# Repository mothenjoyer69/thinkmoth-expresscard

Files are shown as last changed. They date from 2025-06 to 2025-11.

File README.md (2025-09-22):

# ThinkMoth Expresscard to NVMe 
An ExpressCard to NVMe adapter, except this one actually ships! 

The ThinkMoth ExpressCard to NVMe is a low cost, open source adapter for using an M.2 2230/2242 NVMe SSD in an ExpressCard34/54 socket. It features a microSD card slot to enable booting from the SSD, and optional status LEDs for SD and PCIe activity so you can look at cool lights. 

Up to PCIe 3.0 @ 1x is supported (it'll be 2.0 on nearly every machine, though), and the only limitation on drives is power consumption. This board will only provide ~1a @ 3.3v, which can cause issues with higher-performance SSDs.

It also includes a yet-to-be-designed 3D printed chassis, with an EC54-specific version also in the works!

Please note that this board *only* supports NVMe drives!

Update 20/9/25:
Prototype PCBs have been ordered :) 

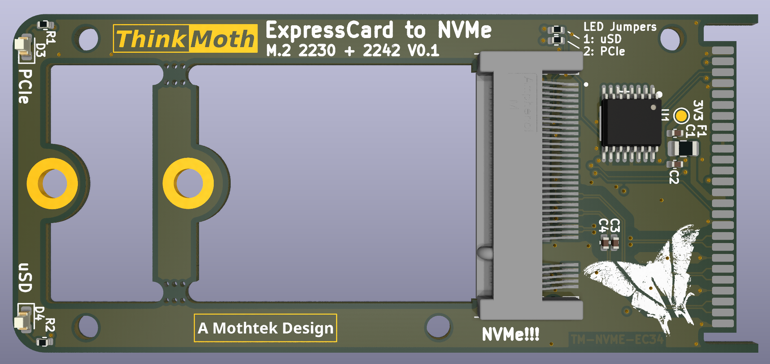
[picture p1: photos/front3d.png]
Front render

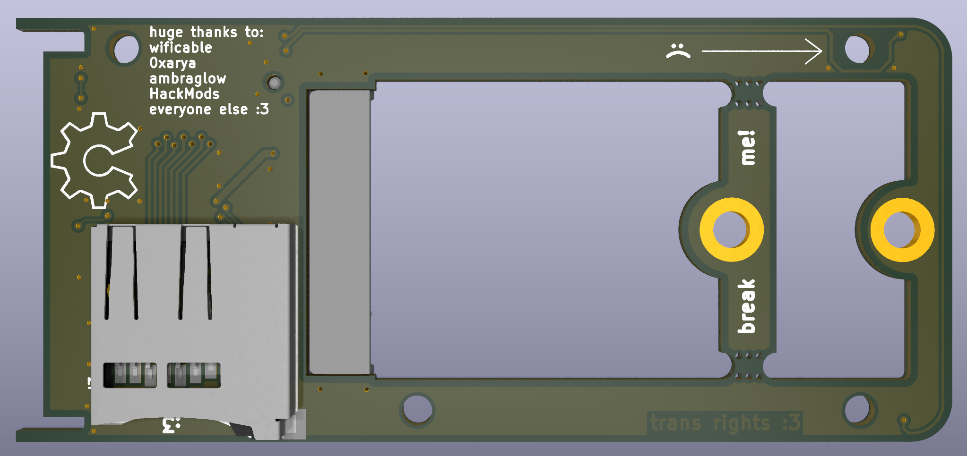
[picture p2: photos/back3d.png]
Back render


# More info:
1. What SSD works best?:
    - ExpressCard is super power limited with only 3v3@1A available to the SSD, so anything slower/low power drives should work fine. Higher end drives might have issues. This adapter only provides a PCIe 1x link, so there isn't much reason to get the high end drives.
2. How does booting from the SSD work?
    - Booting from the SSD works either via a bootloader being installed on the microSD card, which then loads the OS from the SSD. Alternatively, if you are able to add custom drivers, you can use the NVMe driver via Coreboot or similar for basically native operation.
3. When will it be available to buy?
    - I'm planning on having a small batch available in mid October!

# To-do
- Order intitial prototype PCBs [*]
- List on Tindie/Lectronex [ ]
- Alternate versions? [ ]

# Part list:
| Part | Model | Link |
|---|---|---|
| ExpressCard connector  | Amphenol  10030570-2112LF | https://www.arrow.com/en/products/10030570-2112lf/amphenol-fci |
| Mid-mount M.2 M-key | Amphenol MDT180M03001 | https://www.digikey.com.au/en/products/detail/amphenol-cs-fci/MDT180M03001/5810365 |
| SD card controller | Genesys Logic GL823K | https://www.lcsc.com/product-detail/C284879.html |
| microSD card socket | Sofng TF-009 | https://www.lcsc.com/product-detail/C428466.html |
| 1.5A fuse | BHFuse BSMD0805L-150 | https://www.lcsc.com/product-detail/C914095.html |
| 2x 4k 6.3v resistor | Yageo RC0402FR-073KL | https://www.lcsc.com/product-detail/C137987.html |
| 2x 0r 6.3v resistor | Panasonic ERJ2GE0R00X | https://www.lcsc.com/product-detail/C242160.html |
| 4x 0.1uF 6.3v capacitor| Yageo CC0402KRX7R7BB104 | https://www.lcsc.com/product-detail/C60474.html |
| Blue LED | Meihua MHT192WDT-ICE | https://www.lcsc.com/product-detail/C389522.html |
| Pink LED | Xinglight XL-1608UPC-06 | https://www.lcsc.com/product-detail/C2977076.html |

# Doing it yourself:
Wanna do it yourself? Check back here after I've validated the prototype boards, and I'll have a copy of the production gerber .zip, as well as the JLCPCB order settings required!

# Credits
A very big thank you to [Ambra](https://github.com/ambraglow/) for the original board outline, cutout, and EC footprint, and also to [Wifi](https://github.com/a-little-wifi/) and [Arya](https://github.com/CRImier/) and everyone else for all of the help and advice :3

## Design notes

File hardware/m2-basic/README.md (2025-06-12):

# ThinkMoth M.2 2242
An ExpressCard 34/54 board with support for a single M.2 2242 NVMe SSD.

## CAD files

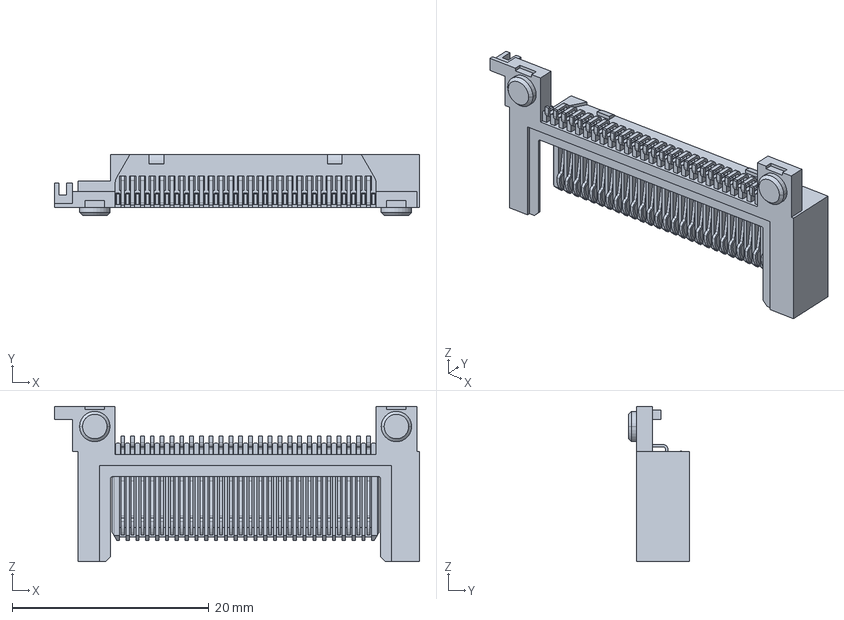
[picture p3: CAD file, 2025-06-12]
hardware/3d-models/c-1759181-1-b-3d.stp
37.1 x 6.20 x 15.8 mm

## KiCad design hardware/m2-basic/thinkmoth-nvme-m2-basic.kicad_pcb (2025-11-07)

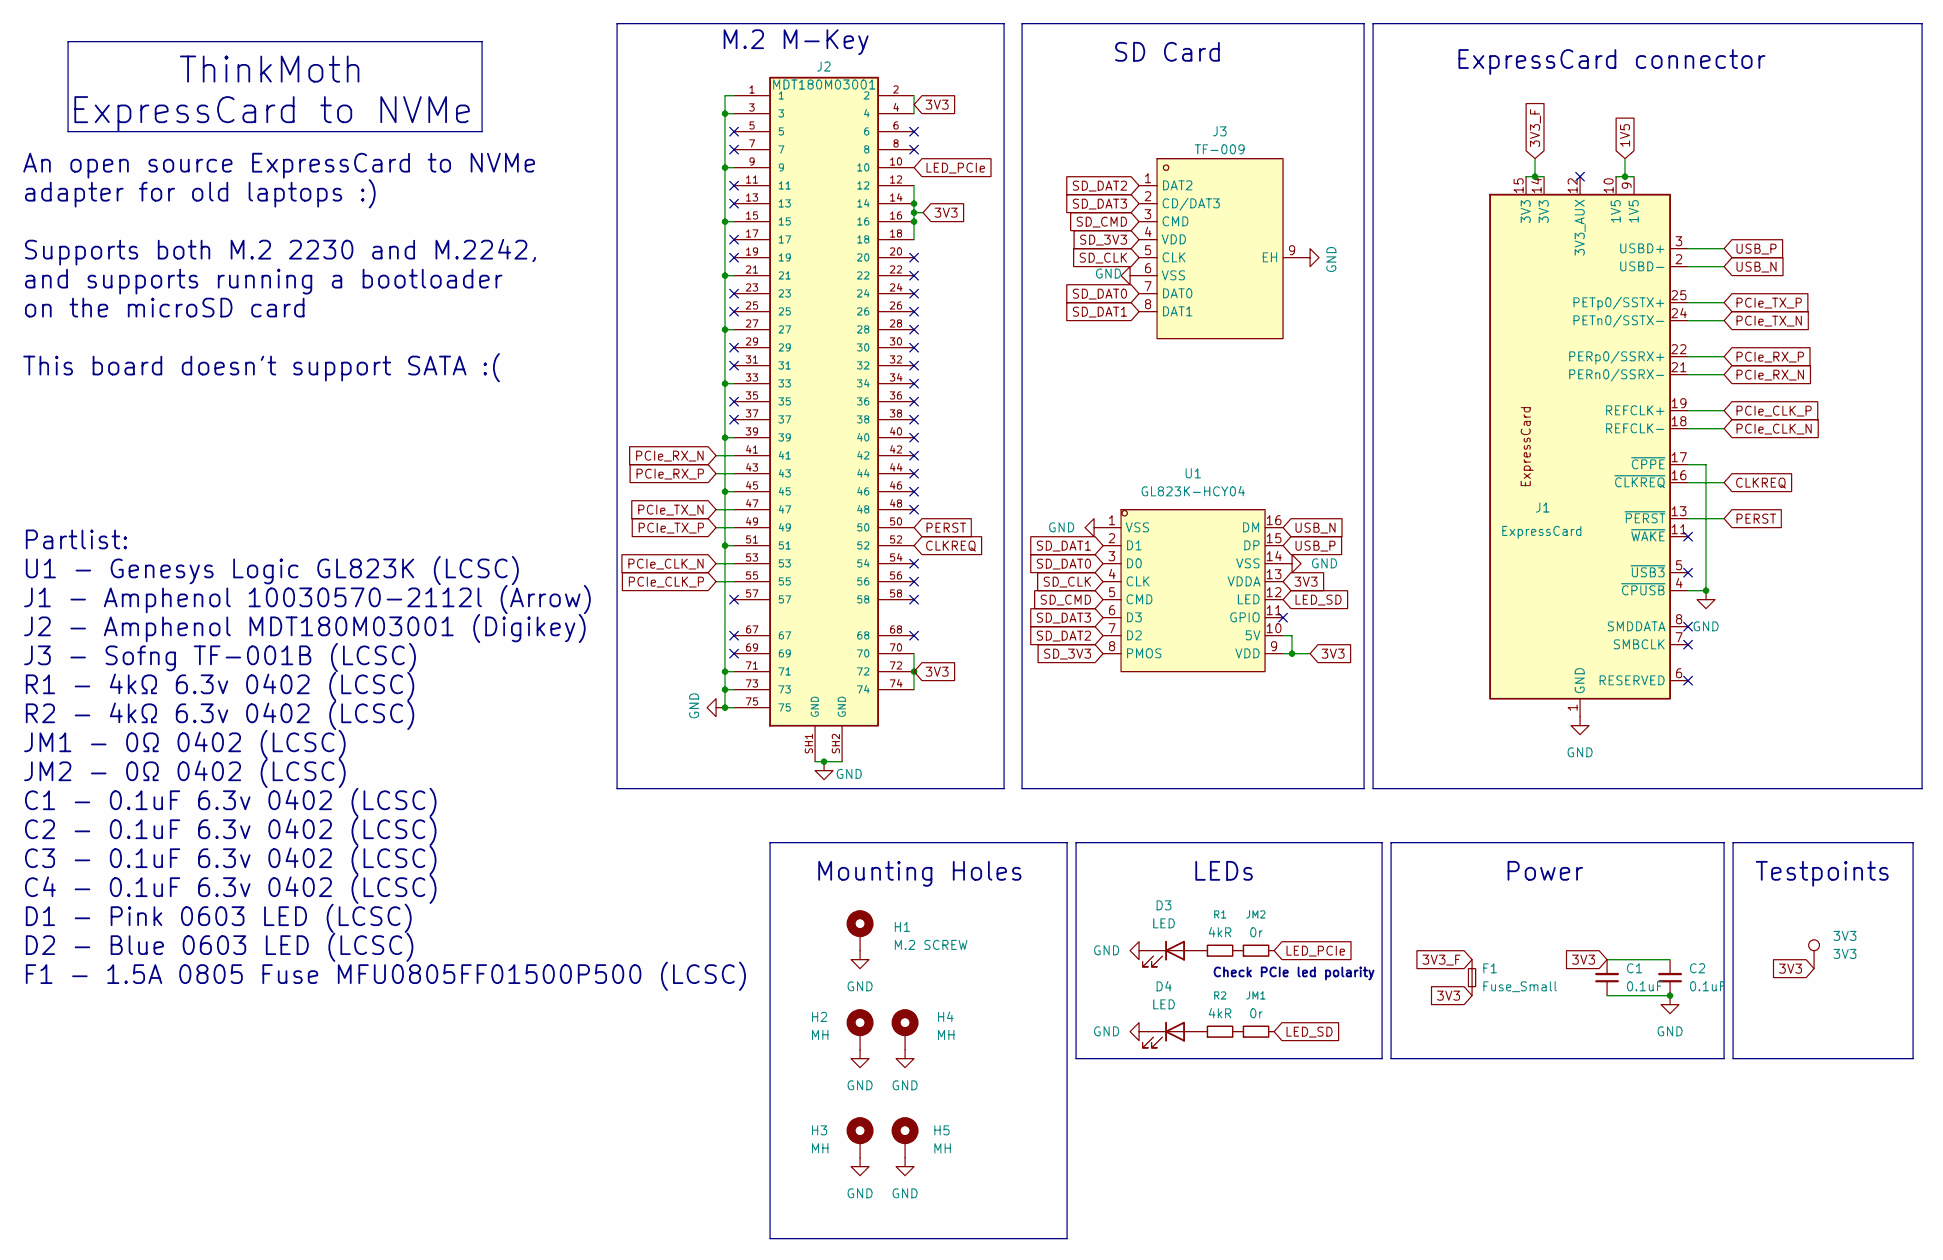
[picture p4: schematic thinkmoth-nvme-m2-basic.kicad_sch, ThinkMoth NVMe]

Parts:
3V3: 3V3; TestPoint_Pad_D1.0mm
C1, C2: 0.1uF; C_0402_1005Metric
D3, D4: LED; LED_0603_1608Metric
F1: Fuse_Small; Fuse_0805_2012Metric
H1: M.2 SCREW; MountingHole_2.7mm_M2.5_DIN965_Pad
H2, H3, H4, H5: MH; MountingHole_2.2mm_M2
J1: ExpressCard; ExpressCard_Plug
J2: MDT180M03001; AMPHENOL_MDT180M03001; PARTREV 2
J3: TF-009; TF-SMD_TF-009; LCSC Part C428466
JM1, JM2: 0r; R_0402_1005Metric
R1, R2: 4kR; R_0402_1005Metric
U1: GL823K-HCY04; SSOP-16_L4.9-W3.9-P0.64-LS6.0-BL; LCSC Part C284879

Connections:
1V5: J1.9 (1V5), J1.10 (1V5)
3V3: 3V3.1, C1.2, C2.2, F1.1, J2.2, J2.4, J2.12, J2.14, J2.16, J2.18, J2.70, J2.72, J2.74, U1.9 (VDD), U1.10 (5V), U1.13 (VDDA)
3V3_F: F1.2, J1.14 (3V3), J1.15 (3V3)
CLKREQ: J1.16 (~CLKREQ), J2.52
GND: C1.1, C2.1, D3.1 (K), D4.1 (K), H1.1, H2.1, H3.1, H4.1, H5.1, J1.1 (GND), J1.4 (~CPUSB), J1.17 (~CPPE), J1.20 (GND), J1.23 (GND), J1.26 (GND), J2.1, J2.3, J2.9, J2.15, J2.21, J2.27, J2.33, J2.39, J2.45, J2.51, J2.71, J2.73, J2.75, J2.SH1 (GND), J2.SH2 (GND), J3.6 (VSS), J3.9 (EH), U1.1 (VSS), U1.14 (VSS)
LED_PCIe: J2.10, JM2.2
LED_SD: JM1.2, U1.12 (LED)
unnamed: D3.2 (A), R1.1
unnamed: D4.2 (A), R2.1
unnamed: JM1.1, R2.2
unnamed: JM2.1, R1.2
PCIe_CLK_N: J1.18 (REFCLK-), J2.53
PCIe_CLK_P: J1.19 (REFCLK+), J2.55
PCIe_RX_N: J1.21 (PERn0/SSRX-), J2.41
PCIe_RX_P: J1.22 (PERp0/SSRX+), J2.43
PCIe_TX_N: J1.24 (PETn0/SSTX-), J2.47
PCIe_TX_P: J1.25 (PETp0/SSTX+), J2.49
PERST: J1.13 (~PERST), J2.50
SD_3V3: J3.4 (VDD), U1.8 (PMOS)
SD_CLK: J3.5 (CLK), U1.4 (CLK)
SD_CMD: J3.3 (CMD), U1.5 (CMD)
SD_DAT0: J3.7 (DAT0), U1.3 (D0)
SD_DAT1: J3.8 (DAT1), U1.2 (D1)
SD_DAT2: J3.1 (DAT2), U1.7 (D2)
SD_DAT3: J3.2 (CD/DAT3), U1.6 (D3)
USB_N: J1.2 (USBD-), U1.16 (DM)
USB_P: J1.3 (USBD+), U1.15 (DP)

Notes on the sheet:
ThinkMoth ExpressCard to NVMe
Mounting Holes
Power
Check PCIe led polarity
M.2 M-Key
An open source ExpressCard to NVMe adapter for old laptops :) Supports both M.2 2230 and M.2242, and supports running a bootloader on the microSD card This board doesn't support SATA :( Partlist: U1 - Genesys Logic GL823K (LCSC) J1 - Amphenol 10030570-2112l (Arrow) J2 - Amphenol MDT180M03001 (Digik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
Testpoints
LEDs
ExpressCard connector
SD Card

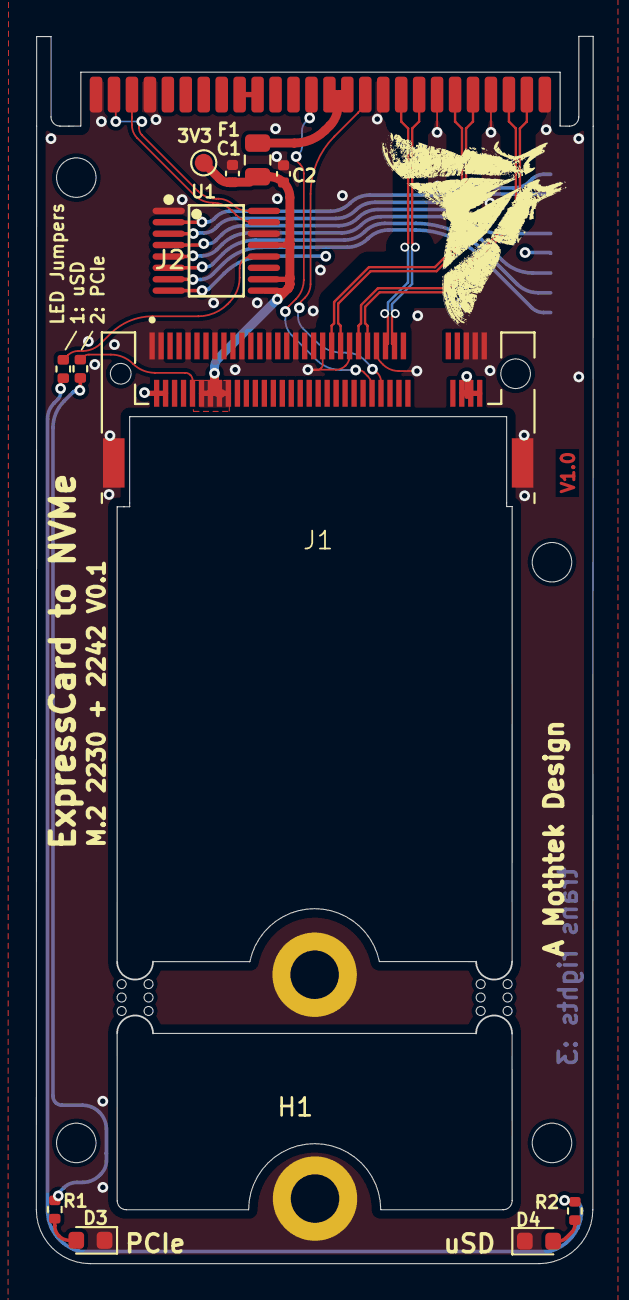
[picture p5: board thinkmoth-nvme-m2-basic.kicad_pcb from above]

Board: 4 copper layers, 31.0 x 68.4 mm, 21 parts (1 on the bottom side), 27 nets.

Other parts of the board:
mouse-bite-2mm-slot, mouse-bite-2mm-slot#2: VAL**; mouse-bite-2mm-slot

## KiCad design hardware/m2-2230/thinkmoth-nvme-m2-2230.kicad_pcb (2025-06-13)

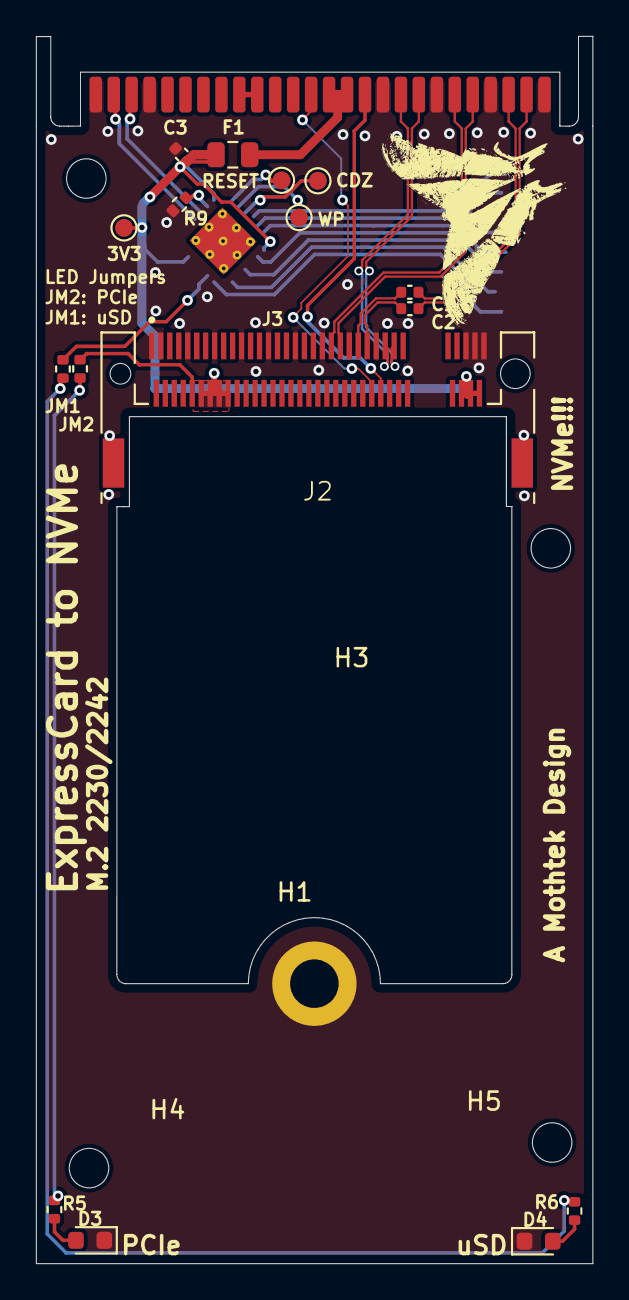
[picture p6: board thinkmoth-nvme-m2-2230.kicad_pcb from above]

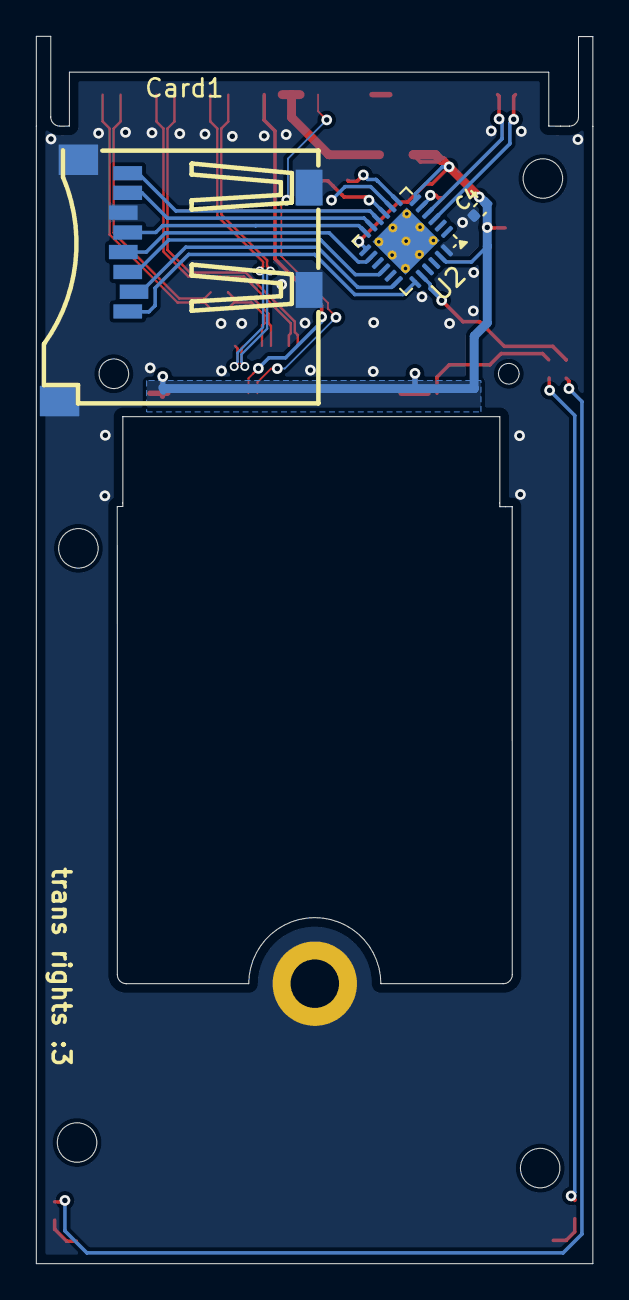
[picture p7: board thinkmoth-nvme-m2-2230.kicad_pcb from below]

Board: 2 copper layers, 31.0 x 68.4 mm, 25 parts (3 on the bottom side), 33 nets.

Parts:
3V3: 3V3; TestPoint_Pad_D1.0mm
C1, C2, C3, C4: 0.1uF; C_0402_1005Metric
CDZ: SD_CDZ; TestPoint_Pad_D1.0mm
Card1: TF-001B; TF-SMD_TF-001B
D3, D4: LED; LED_0603_1608Metric
F1: Fuse_Small; Fuse_0805_2012Metric
H1: M.2 SCREW; MountingHole_2.7mm_M2.5_DIN965_Pad
H2, H3, H4, H5: MOUNTING SCREW; MountingHole_2.2mm_M2
J2: ExpressCard; ExpressCard_Plug
J3: MDT180M03001; AMPHENOL_MDT180M03001
JM1, JM2: 0r; R_0402_1005Metric
R5, R6: 4kR; R_0402_1005Metric
R9: 680r; R_0402_1005Metric
RESET: SD_RESET; TestPoint_Pad_D1.0mm
U2: QFN-24-1EP_4x4mm_P0.5mm_EP2.7x2.6mm_ThermalVias
WP: SD_WP; TestPoint_Pad_D1.0mm

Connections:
1V5: J2.9 (1V5), J2.10 (1V5)
3V3: 3V3.1, C3.2, C4.2, F1.1, J3.2, J3.4, J3.12, J3.14, J3.16, J3.18, J3.70, J3.72, J3.74, U2.6 (AVDD), U2.13 (DVDD), U2.23 (DVDD)
3V3_F: F1.2, J2.14 (3V3), J2.15 (3V3)
CLKREQ: J2.16 (~CLKREQ), J3.52
GND: C3.1, C4.1, Card1.6 (VSS), Card1.9 (SHIELD), Card1.10 (SHIELD), Card1.11 (SW), Card1.12 (SW), D3.1 (K), D4.1 (K), H1.1, J2.1 (GND), J2.4 (~CPUSB), J2.17 (~CPPE), J2.20 (GND), J2.23 (GND), J2.26 (GND), J3.1, J3.3, J3.9, J3.15, J3.21, J3.27, J3.33, J3.39, J3.45, J3.51, J3.71, J3.73, J3.75, R9.1, U2.24 (GND)
unnamed: D3.2 (A), R5.1
unnamed: D4.2 (A), R6.1
unnamed: JM1.1, R6.2
unnamed: JM2.1, R5.2
unnamed: R9.2, U2.5 (RREF)
PCIe_CLK_N: J2.18 (REFCLK-), J3.53
PCIe_CLK_P: J2.19 (REFCLK+), J3.55
PCIe_LED: J3.10, JM2.2
PCIe_RX_N: J2.21 (PERn0/SSRX-), J3.41
PCIe_RX_P: J2.22 (PERp0/SSRX+), J3.43
PCIe_TX_C_N: C1.1, J2.24 (PETn0/SSTX-)
PCIe_TX_C_P: C2.1, J2.25 (PETp0/SSTX+)
PCIe_TX_N: C1.2, J3.47
PCIe_TX_P: C2.2, J3.49
PERST: J2.13 (~PERST), J3.50
SD_3V3: Card1.4 (VDD), U2.14 (PMOS)
SD_CDZ: CDZ.1, U2.9 (SD_CDZ)
SD_CLK: Card1.5 (CLK), U2.12 (SD_CLK)
SD_CMD: Card1.3 (CMD), U2.16 (SD_CMD)
SD_DAT0: Card1.7 (DAT0), U2.11 (D0)
SD_DAT1: Card1.8 (DAT1), U2.10 (D1)
SD_DAT2: Card1.1 (DAT2), U2.19 (D2)
SD_DAT3: Card1.2 (CD/DAT3), U2.18 (D3)
SD_LED: JM1.2, U2.20 (LED)
SD_RESET: RESET.1, U2.7 (RSTZ)
SD_WP: U2.8 (SD_WP), WP.1
USB_N: J2.2 (USBD-), U2.3 (DM)
USB_P: J2.3 (USBD+), U2.4 (DP)

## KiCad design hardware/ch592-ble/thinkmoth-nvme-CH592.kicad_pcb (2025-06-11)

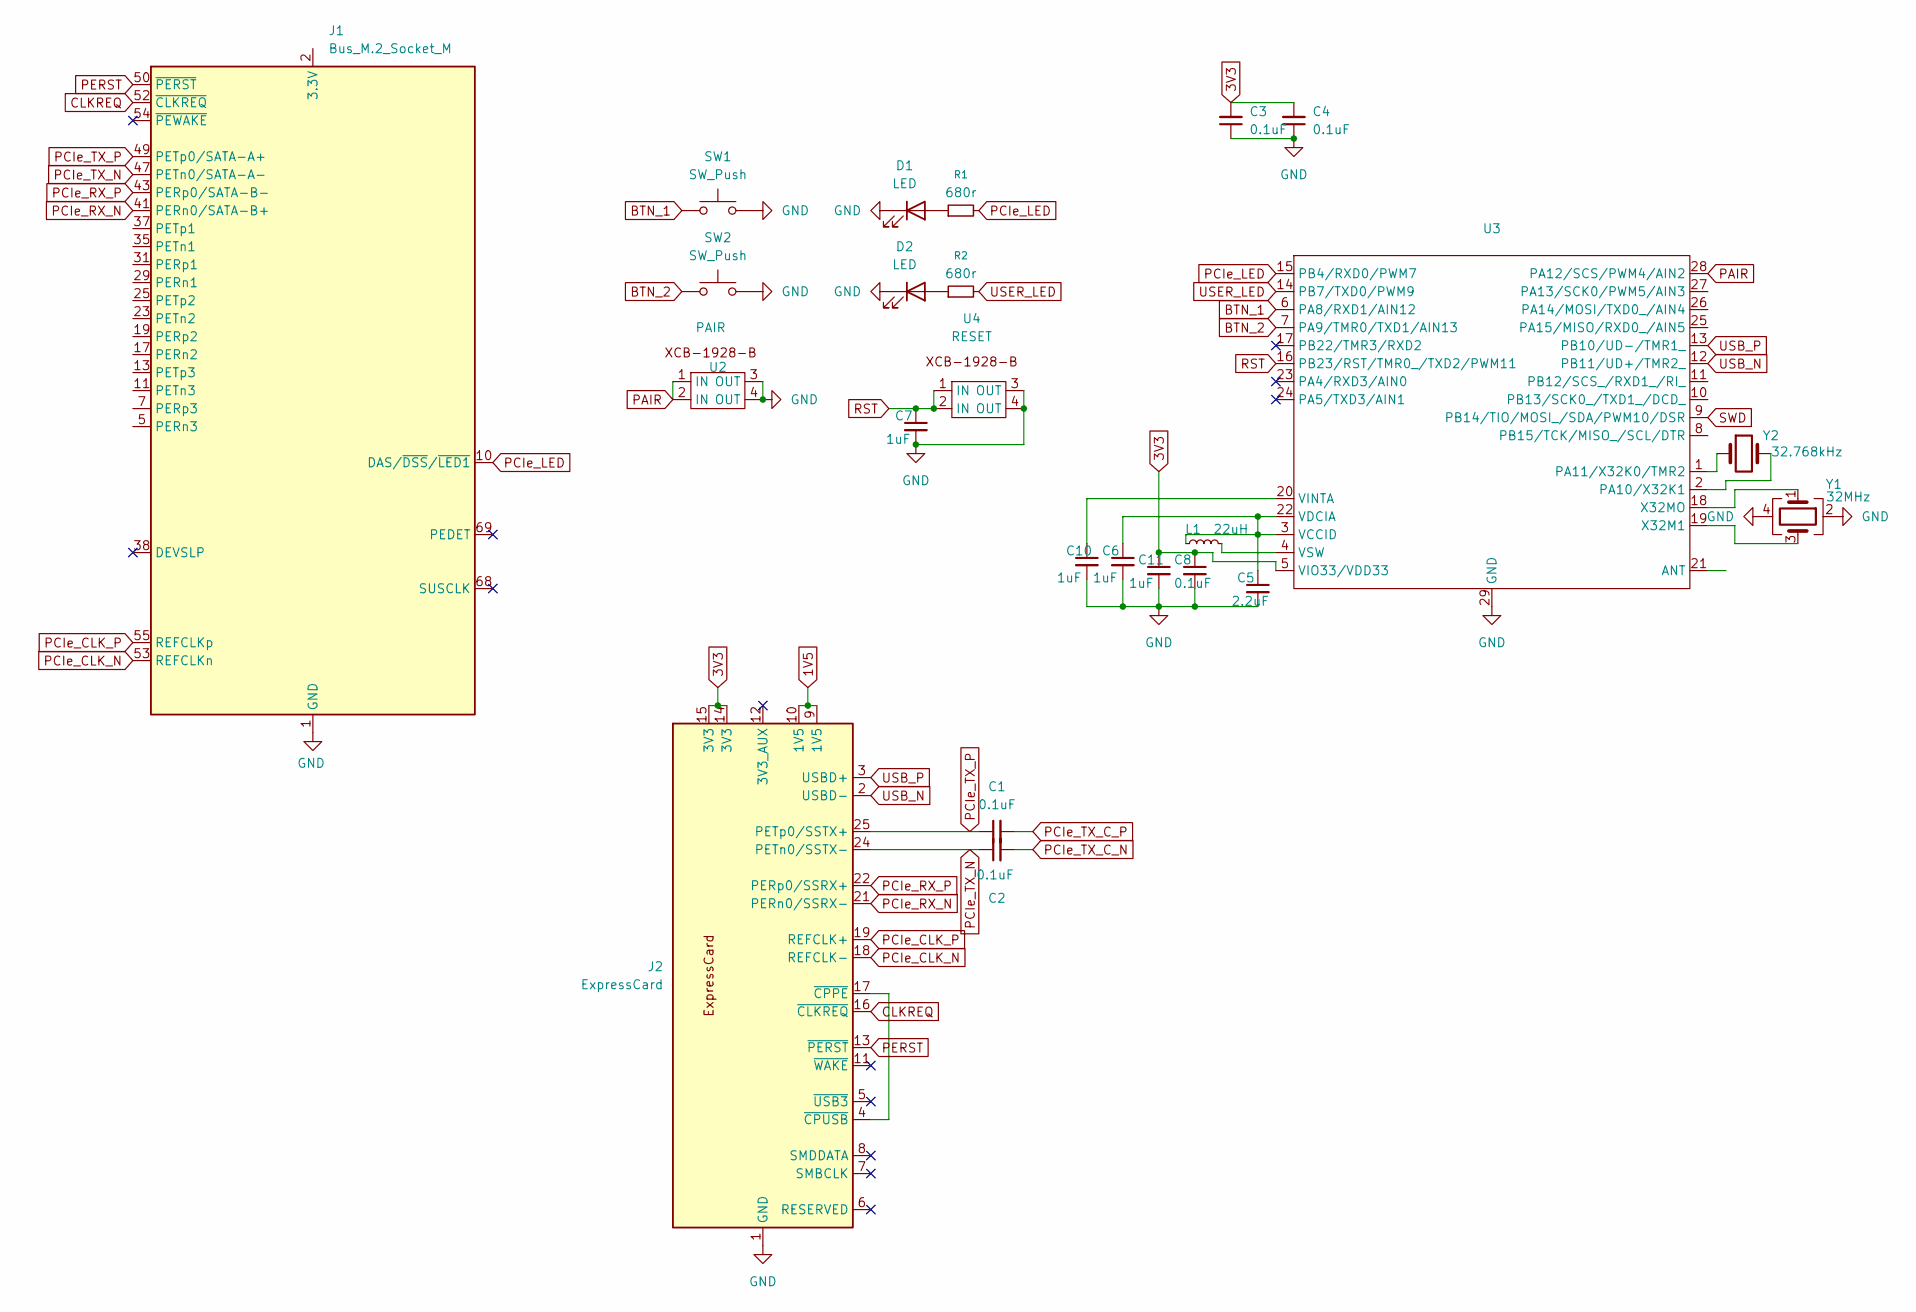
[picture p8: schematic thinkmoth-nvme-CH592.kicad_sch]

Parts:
C1, C2, C3, C4, C8: 0.1uF; C_0402_1005Metric
C5: 2.2uF; C_0402_1005Metric
C6, C7, C10, C11: 1uF; C_0402_1005Metric
D1, D2: LED; LED_0402_1005Metric
J1: Bus_M.2_Socket_M; CONN-SMD_APCI0159-P001A
J2: ExpressCard; ExpressCard_Plug
L1: 22uH; L_0603_1608Metric
R1, R2: 680r; R_0402_1005Metric
SW1, SW2: SW_Push
U2: PAIR; KEY-SMD_4P-L2.8-W2.0-P1.20-LS3.0-TL
U3: QFN-28-1EP_4x4mm_P0.4mm_EP2.3x2.3mm
U4: RESET; KEY-SMD_4P-L2.8-W2.0-P1.20-LS3.0-TL
Y1: 32MHz; Crystal_SMD_1210-4Pin_1.2x1.0mm
Y2: 32.768kHz; Crystal_SMD_2012-2Pin_2.0x1.2mm

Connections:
1V5: J2.9 (1V5), J2.10 (1V5)
3V3: C3.2, C4.2, C8.1, C11.1, J2.14 (3V3), J2.15 (3V3), U3.5 (VIO33/VDD33)
BTN_1: SW1.1, U3.6 (PA8/RXD1/AIN12)
BTN_2: SW2.1, U3.7 (PA9/TMR0/TXD1/AIN13)
CLKREQ: J1.52 (~CLKREQ), J2.16 (~CLKREQ)
GND: C3.1, C4.1, C5.2, C6.2, C7.2, C8.2, C10.2, C11.2, D1.1 (K), D2.1 (K), J1.1 (GND), J1.3 (GND), J1.9 (GND), J1.15 (GND), J1.21 (GND), J1.27 (GND), J1.33 (GND), J1.39 (GND), J1.45 (GND), J1.51 (GND), J1.57 (GND), J1.71 (GND), J1.73 (GND), J1.75 (GND), J2.1 (GND), J2.20 (GND), J2.23 (GND), J2.26 (GND), SW1.2, SW2.2, U2.3 (OUT), U2.4 (OUT), U3.29 (GND), U4.3 (OUT), U4.4 (OUT), Y1.2, Y1.4
unnamed: D1.2 (A), R1.1
unnamed: D2.2 (A), R2.1
unnamed: J1.2 (3.3V), J1.4 (3.3V), J1.12 (3.3V), J1.14 (3.3V), J1.16 (3.3V), J1.18 (3.3V), J1.70 (3.3V), J1.72 (3.3V), J1.74 (3.3V)
unnamed: J2.4 (~CPUSB), J2.17 (~CPPE)
unnamed: U3.2 (PA10/X32K1), Y2.2
unnamed: U3.1 (PA11/X32K0/TMR2), Y2.1
unnamed: C5.1, C6.1, L1.1, U3.3 (VCCID), U3.22 (VDCIA)
unnamed: C10.1, U3.20 (VINTA)
unnamed: L1.2, U3.4 (VSW)
unnamed: U3.19 (X32M1), Y1.3
unnamed: U3.18 (X32MO), Y1.1
PAIR: U2.1 (IN), U2.2 (IN), U3.28 (PA12/SCS/PWM4/AIN2)
PCIe_CLK_N: J1.53 (REFCLKn), J2.18 (REFCLK-)
PCIe_CLK_P: J1.55 (REFCLKp), J2.19 (REFCLK+)
PCIe_LED: J1.10 (DAS/~DSS/~LED1), R1.2, U3.15 (PB4/RXD0/PWM7)
PCIe_RX_N: J1.41 (PERn0/SATA-B+), J2.21 (PERn0/SSRX-)
PCIe_RX_P: J1.43 (PERp0/SATA-B-), J2.22 (PERp0/SSRX+)
PCIe_TX_C_N: C2.2
PCIe_TX_C_P: C1.2
PCIe_TX_N: C2.1, J1.47 (PETn0/SATA-A-), J2.24 (PETn0/SSTX-)
PCIe_TX_P: C1.1, J1.49 (PETp0/SATA-A+), J2.25 (PETp0/SSTX+)
PERST: J1.50 (~PERST), J2.13 (~PERST)
RST: C7.1, U3.16 (PB23/RST/TMR0_/TXD2/PWM11), U4.1 (IN), U4.2 (IN)
SWD: U3.9 (PB14/TIO/MOSI_/SDA/PWM10/DSR)
USB_N: J2.2 (USBD-), U3.12 (PB11/UD+/TMR2_)
USB_P: J2.3 (USBD+), U3.13 (PB10/UD-/TMR1_)
USER_LED: R2.2, U3.14 (PB7/TXD0/PWM9)

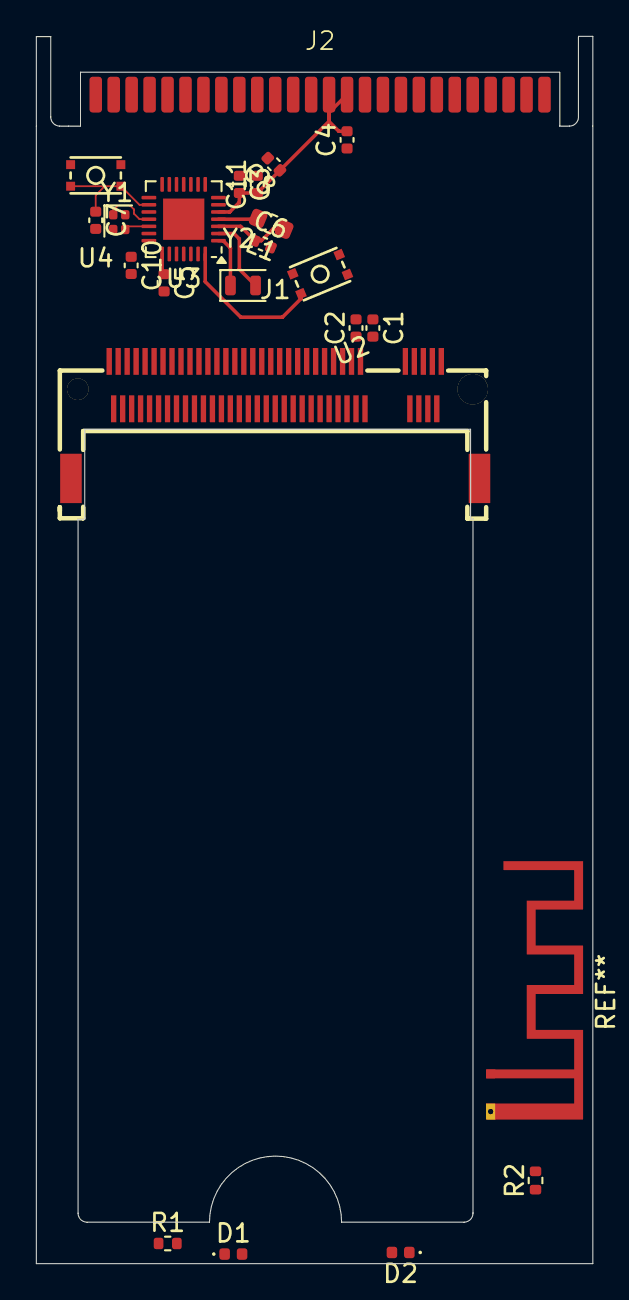
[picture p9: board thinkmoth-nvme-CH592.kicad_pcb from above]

Board: 2 copper layers, 31.0 x 68.4 mm, 22 parts (0 on the bottom side), 28 nets.

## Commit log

2025-06-11 initial commit, add files, add readme
    [thinkmoth-nvme-CH592.kicad_pcb, thinkmoth-nvme-CH592.kicad_sch, thinkmoth-nvme-m2-2230.kicad_pcb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]
2025-06-12 add TE expresscard 3d model
    [c-1759181-1-b-3d.stp]
2025-06-13 combined m.2 2230 and 2242 design, wip
    [thinkmoth-nvme-m2-2242.kicad_pcb, thinkmoth-nvme-m2-2242.kicad_sch]
2025-06-13 keeping legacy m.2 2230 design around... for now
    [thinkmoth-nvme-m2-2230.kicad_pcb]
2025-06-13 change naming + move boards to archive folder
    [thinkmoth-nvme-CH592.kicad_pcb, thinkmoth-nvme-CH592.kicad_sch, thinkmoth-nvme-m2-2230.kicad_pcb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]
2025-06-13 m.2-basic: updated layout, moved mounting holes
    [thinkmoth-nvme-m2-basic.kicad_pcb, thinkmoth-nvme-m2-basic.kicad_sch]
2025-06-13 add wip board render
2025-06-13 m.2-basic: slight silkscreen tweak
    [thinkmoth-nvme-m2-basic.kicad_pcb]
2025-06-13 m.2-basic: schematic clean up
    [thinkmoth-nvme-m2-basic.kicad_sch]
2025-06-15 m.2-basic: minor layout tweaks, schem update
    [thinkmoth-nvme-m2-basic.kicad_pcb, thinkmoth-nvme-m2-basic.kicad_sch]
2025-06-17 updates for prototype run
    [thinkmoth-nvme-m2-basic.kicad_pcb, thinkmoth-nvme-m2-basic.kicad_sch]
2025-09-05 minor tweaks
    [thinkmoth-nvme-m2-basic.kicad_pcb, thinkmoth-nvme-m2-basic.kicad_sch]
2025-09-22 README.md: added part list, changed some stuff
    [thinkmoth-nvme-CH592.kicad_pcb, thinkmoth-nvme-CH592.kicad_sch, thinkmoth-nvme-m2-2230.kicad_pcb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]
2025-11-07 Fixed PCIe caps that shouldn't exist, minor routing tweaks
    [thinkmoth-nvme-m2-basic.kicad_pcb, thinkmoth-nvme-m2-basic.kicad_sch]
